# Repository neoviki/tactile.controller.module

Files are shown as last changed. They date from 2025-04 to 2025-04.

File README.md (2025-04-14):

# Tactile Controller Module

The Tactile Controller Module is an interface board designed to read tactile sensor data from a dedicated sensor module containing 36 sensors (currently under development and not yet publicly available). It is powered by the PIC32MM0256GPM036 microcontroller in a UQFN 40-pin package. The module is built to sample and manage data from high-density tactile sensor arrays, offering flexible communication options via I²C, hardware SPI (HW SPI), and software SPI (SW SPI) protocols.

## Features

- **Microcontroller:** PIC32MM0256GPM036 (UQFN-40)  
- **Protocols Supported:**
  - I²C  
  - Hardware SPI (HW SPI)  
  - Software SPI (SW SPI)  
- **Application:** 
  - Interfaces with high-density tactile sensor arrays  
  - Suitable for applications requiring customizable sampling and interfacing logic  

## Use Case

The controller module is primarily used to sample sensor data from a high-density tactile sensing module with 36 sensors. It communicates with the tactile sensing module using a software SPI protocol. Designed for applications such as robotics, touch-sensitive interfaces, and pressure-mapping systems, the tactile sensing module provides detailed tactile measurements, specifically pressure data. The controller runs essential firmware to acquire and format the sampled data, and transmits the tactile sensor data to an external system (such as a connected computer or robot) via a hardware SPI protocol.

## Board Images

**Populated Module**  
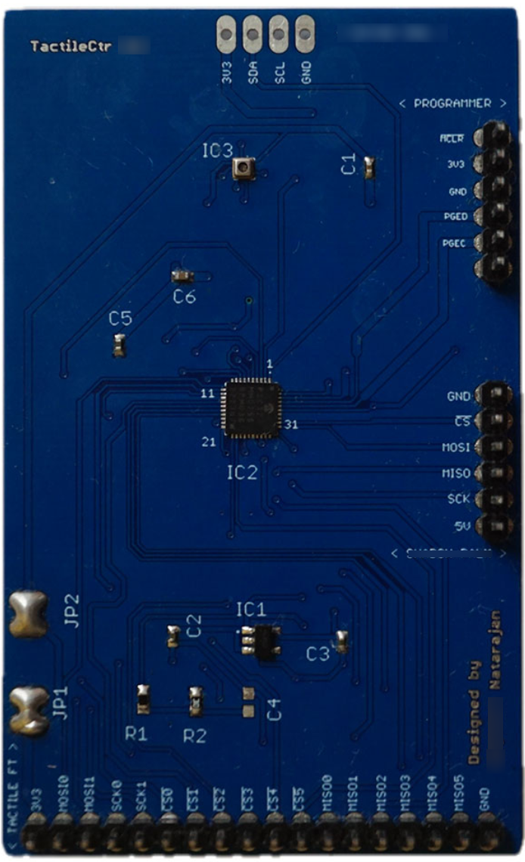
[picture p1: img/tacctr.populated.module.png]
Populated Module


**Board Layout**  
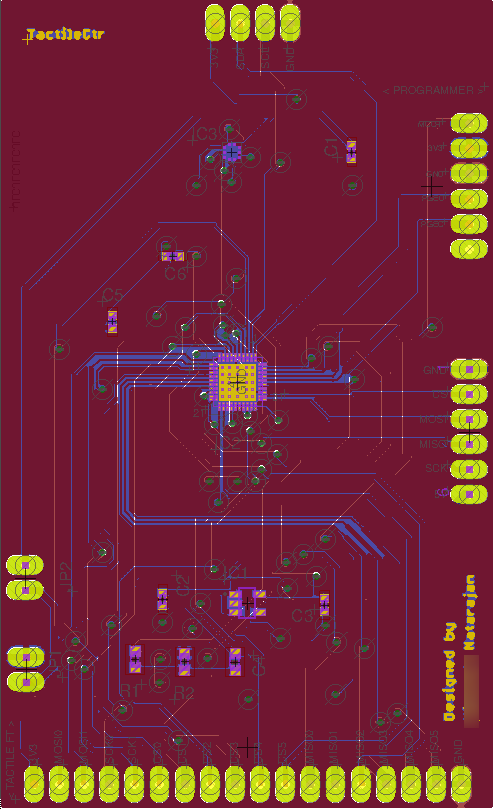
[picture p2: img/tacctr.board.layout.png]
Board Layout


**Schematics**  
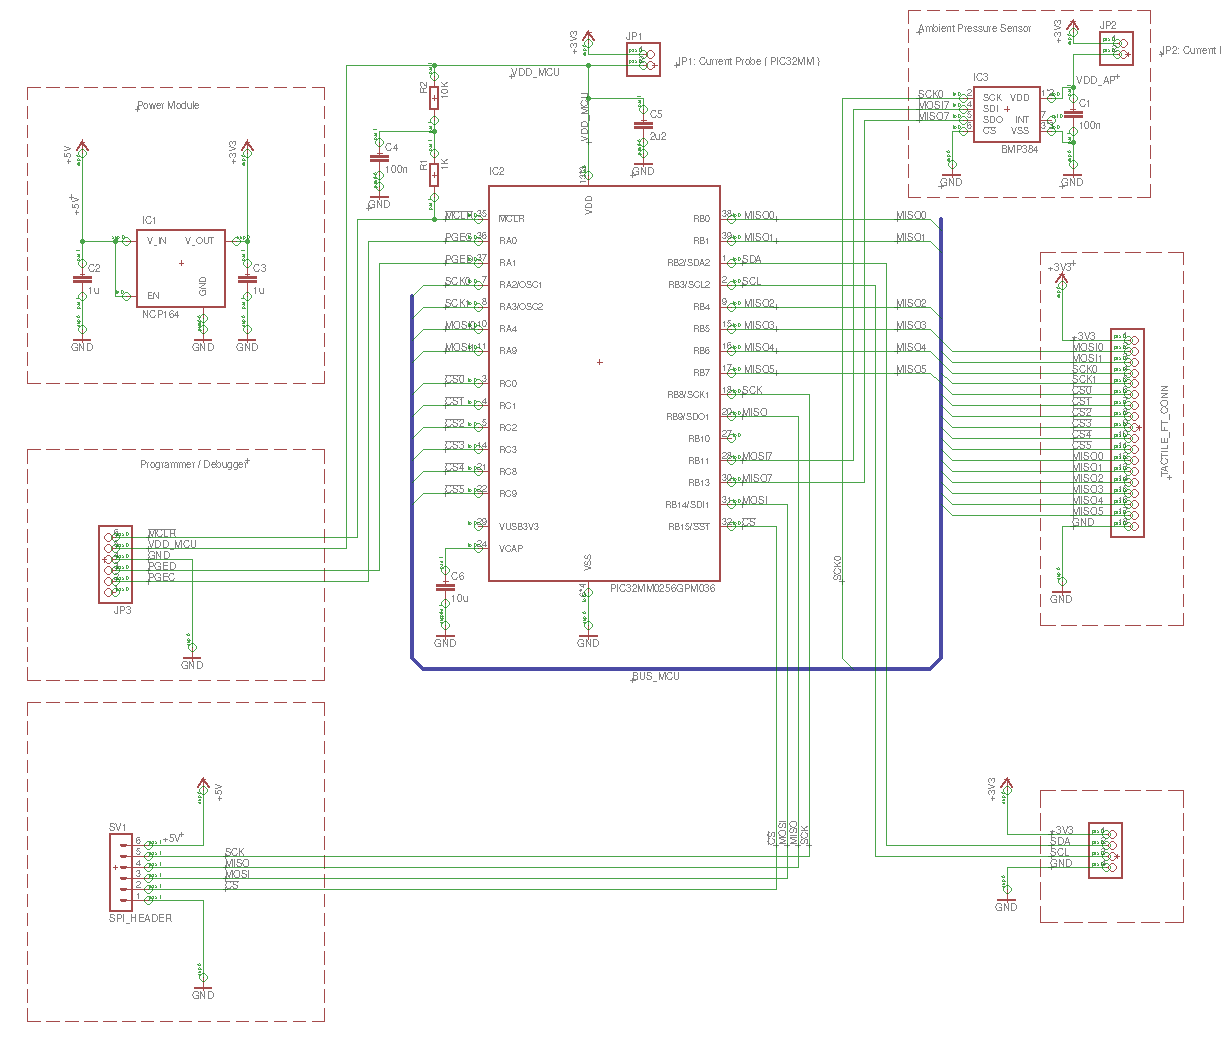
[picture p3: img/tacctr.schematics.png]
Schematics


## Additional Details

- **Pin headers** are provided for programming the MCU and interfacing with external sensors and components.  
- **Low-power operation** and compact form factor make it ideal for embedded systems and portable tactile solutions.  
- Firmware development and sensor interfacing can be customized based on specific application needs.

---

## License

This project is licensed under the **BSD 2-Clause License**.  
See the [`LICENSE`](LICENSE) file for full license text.

## Usage and Attribution

You are welcome to **use, modify, or build upon this design** for personal, academic, or commercial purposes.  
If you use or adapt any part of this work, **please credit the original author**:

**V. Natarajan**

For academic usage, you may cite this repository using the following BibTeX entry:

```bibtex
@misc{vnatarajan_tactile_controller_module,
  author       = {V. Natarajan},
  title        = {Tactile Controller Module},
  year         = {2025},
  howpublished = {\url{https://github.com/neoviki/tactile.controller.module}},
  note         = {Accessed: 2025-04-11}

}
```

> 📎 Attribution helps support and recognize open-source contributions — thank you!

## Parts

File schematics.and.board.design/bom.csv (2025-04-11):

Part | Value | Device | Quantity
ACTIVE_NAIL_CONN |  | PINHD-1X4/90 | 1
C1 | 100n | C-EUC0402 | 1
C2 | 1u | C-EUC0402 | 2
C4 | 1u | C-EUC0603 | 1
C5 | 2u2 | C-EUC0402 | 1
C6 | 10u | C-EUC0402 | 1
IC1 | NCP164 | NCP164_3.3V_REGULATOR | 1
IC2 | PIC32MM0256GPM036 | PIC32MM";"PIC32MM0256GPM036_UQFN_40PIN | 1
IC3 | BMP384 | BMP384 | 1
JP1 |  | PINHD-1X2 | 1
JP2 |  | PINHD-1X2 | 1
R1 | 1K | R-EU_R0603 | 1
R2 | 10K | R-EU_R0603 | 1
SV1 | SPI_HEADER | MA06-1 | 1
SV2 | 53261-05 | 53261-05 | 1
TACTILE_FT_CONN |  | PINHD-1X18/90 | 1

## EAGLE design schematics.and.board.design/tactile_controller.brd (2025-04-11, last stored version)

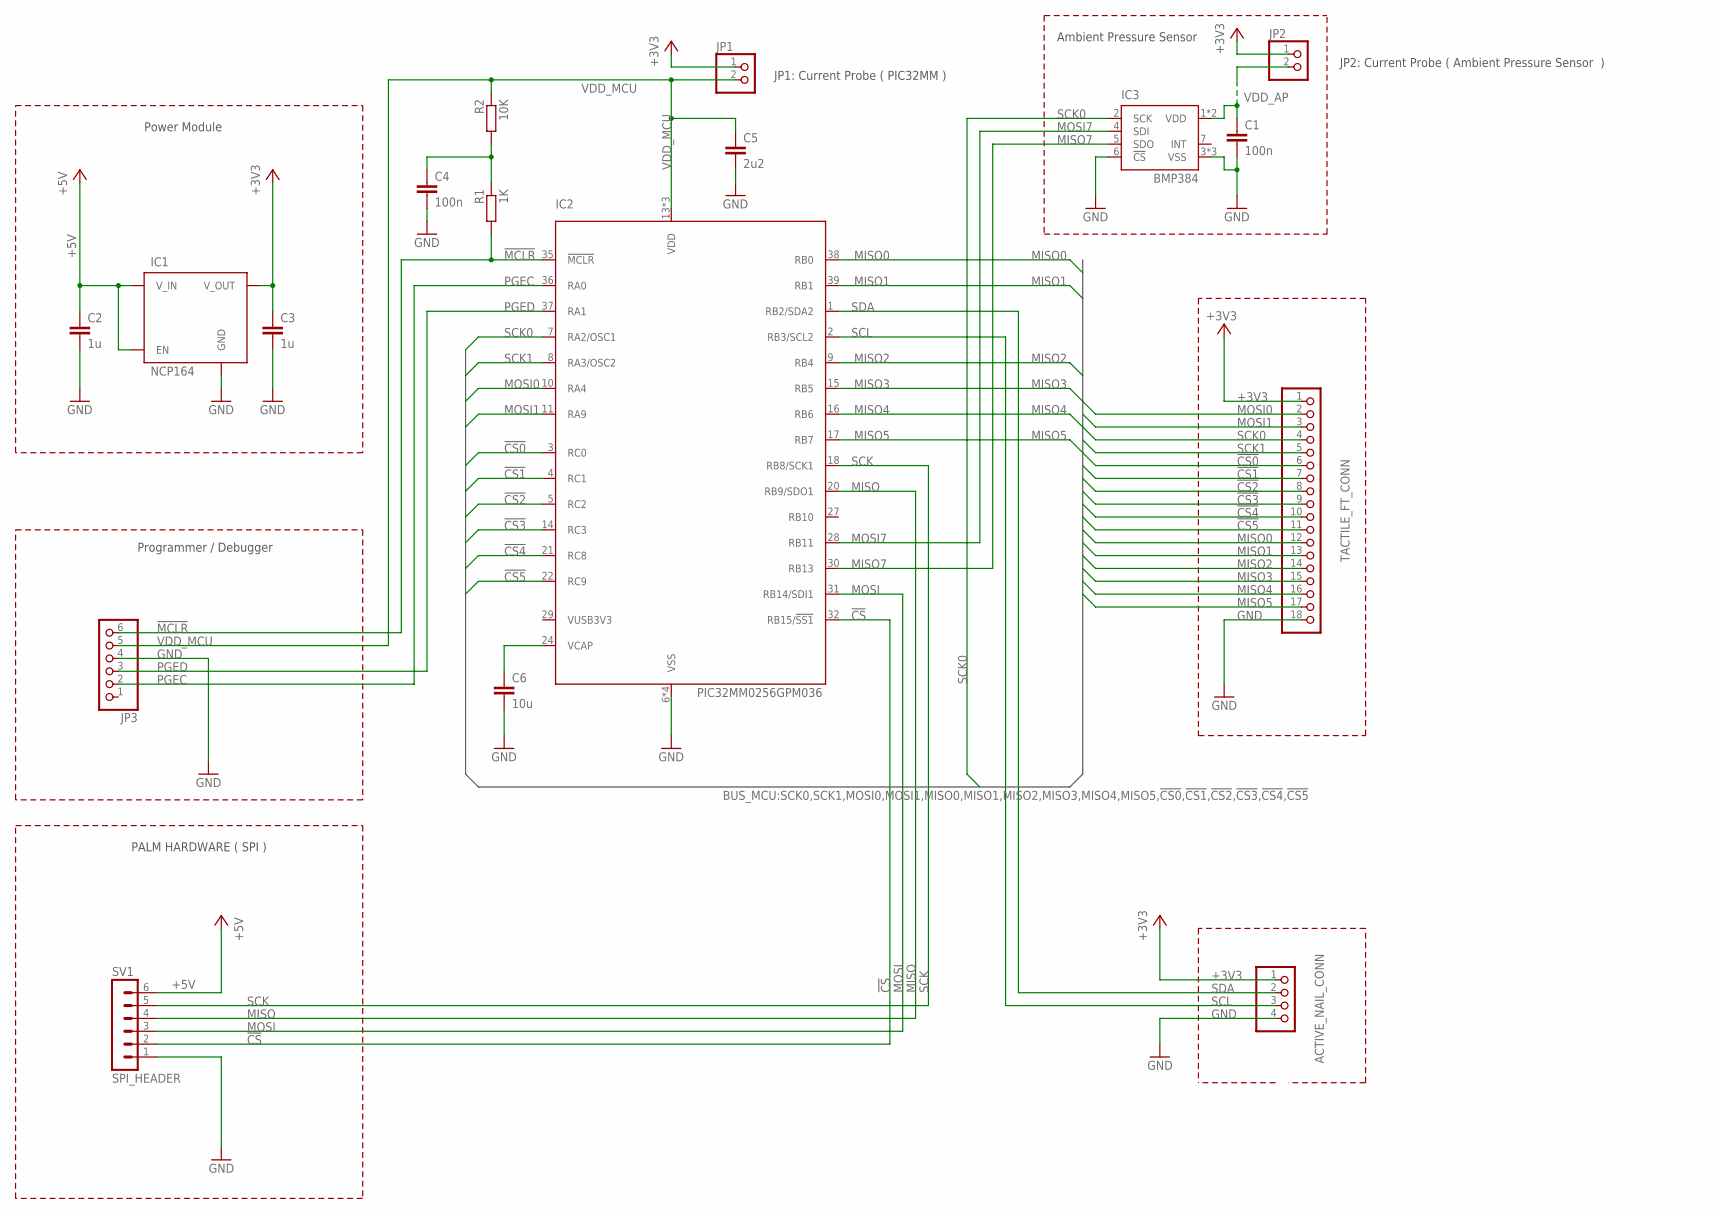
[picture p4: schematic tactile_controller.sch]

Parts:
ACTIVE_NAIL_CONN: PINHD-1X4/90; 1X04/90
C1: 100n; C0402
C2, C3: 1u; C0402
C4: 100n; C0603
C5: 2u2; C0402
C6: 10u; C0402
IC1: NCP164; NCP164_3.3V_REGULATOR_TSOP5
IC2: PIC32MM0256GPM036; PIC32MM0256GPM036_UQFN_40PIN
IC3: BMP384
JP1, JP2: 1X02
JP3: PINHD-1X6/90; 1X06/90
R1: 1K; R0603
R2: 10K; R0603
SV1: SPI_HEADER; MA06-1
TACTILE_FT_CONN: PINHD-1X18/90; 1X18/90

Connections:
!CS: IC2.32 (RB15/!SS1), SV1.2
!CS0: IC2.3 (RC0), TACTILE_FT_CONN.6
!CS1: IC2.4 (RC1), TACTILE_FT_CONN.7
!CS2: IC2.5 (RC2), TACTILE_FT_CONN.8
!CS3: IC2.14 (RC3), TACTILE_FT_CONN.9
!CS4: IC2.21 (RC8), TACTILE_FT_CONN.10
!CS5: IC2.22 (RC9), TACTILE_FT_CONN.11
!MCLR: IC2.35 (!MCLR), JP3.6, R1.2
+3V3: ACTIVE_NAIL_CONN.1, C3.1, IC1.5 (V_OUT), JP1.1, JP2.1, TACTILE_FT_CONN.1
+5V: C2.1, IC1.1 (V_IN), IC1.3 (EN), SV1.6
GND: ACTIVE_NAIL_CONN.4, C1.2, C2.2, C3.2, C4.2, C5.2, C6.2, IC1.2 (GND), IC2.6 (VSS), IC2.12 (VSS), IC2.33 (VSS), IC2.41 (VSS), IC3.3 (VSS), IC3.6 (!CS), IC3.8 (VSS), IC3.9 (VSS), JP3.4, SV1.1, TACTILE_FT_CONN.18
MISO: IC2.20 (RB9/SDO1), SV1.4
MISO0: IC2.38 (RB0), TACTILE_FT_CONN.12
MISO1: IC2.39 (RB1), TACTILE_FT_CONN.13
MISO2: IC2.9 (RB4), TACTILE_FT_CONN.14
MISO3: IC2.15 (RB5), TACTILE_FT_CONN.15
MISO4: IC2.16 (RB6), TACTILE_FT_CONN.16
MISO5: IC2.17 (RB7), TACTILE_FT_CONN.17
MISO7: IC2.30 (RB13), IC3.5 (SDO)
MOSI: IC2.31 (RB14/SDI1), SV1.3
MOSI0: IC2.10 (RA4), TACTILE_FT_CONN.2
MOSI1: IC2.11 (RA9), TACTILE_FT_CONN.3
MOSI7: IC2.28 (RB11), IC3.4 (SDI)
unnamed: C4.1, R1.1, R2.2
unnamed: C6.1, IC2.24 (VCAP)
PGEC: IC2.36 (RA0), JP3.2
PGED: IC2.37 (RA1), JP3.3
SCK: IC2.18 (RB8/SCK1), SV1.5
SCK0: IC2.7 (RA2/OSC1), IC3.2 (SCK), TACTILE_FT_CONN.4
SCK1: IC2.8 (RA3/OSC2), TACTILE_FT_CONN.5
SCL: ACTIVE_NAIL_CONN.3, IC2.2 (RB3/SCL2)
SDA: ACTIVE_NAIL_CONN.2, IC2.1 (RB2/SDA2)
VDD_AP: C1.1, IC3.1 (VDD), IC3.10 (VDD), JP2.2
VDD_MCU: C5.1, IC2.13 (VDD), IC2.26 (VDD), IC2.34 (VDD), JP1.2, JP3.5, R2.1

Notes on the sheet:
Power Module
Programmer / Debugger
PALM HARDWARE ( SPI )
Ambient Pressure Sensor
JP1: Current Probe ( PIC32MM )
JP2: Current Probe ( Ambient Pressure Sensor )

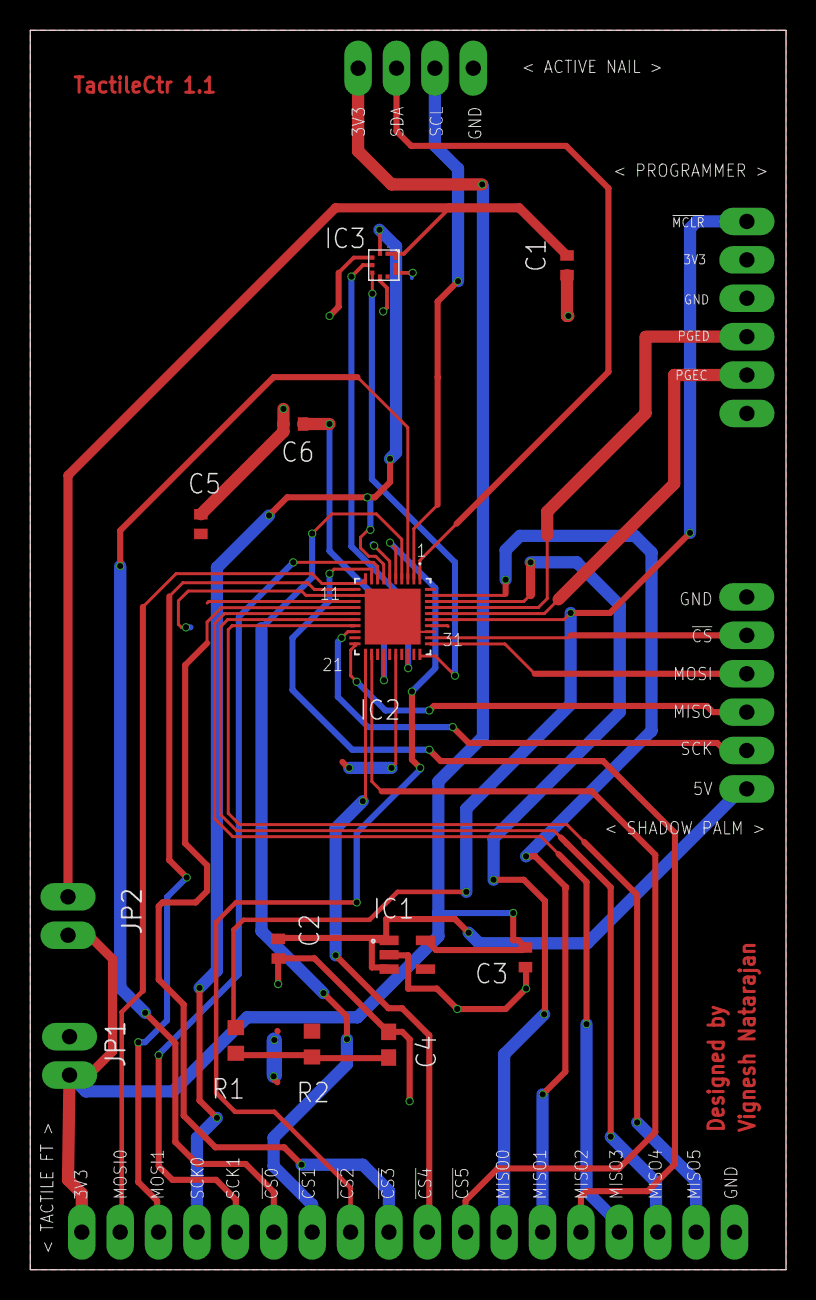
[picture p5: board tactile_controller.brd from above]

Board: 2 copper layers, 50.0 x 82.0 mm, 17 parts (0 on the bottom side), 34 nets.

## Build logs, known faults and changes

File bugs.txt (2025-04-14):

# Bugs

In Tactile CTR the following PINS are not working

 MOSI0 : RA4
 MISO2 : RB4

 According to datasheet "RA4 and RB4 pins are controlled by the SOSC": SOSC is clock

 in the next hardware don't use RA4 and RB4.

# Recommendation

 Also don't use RB11 and RB13 ( I didn't test these pins, it might work but try not to use )
